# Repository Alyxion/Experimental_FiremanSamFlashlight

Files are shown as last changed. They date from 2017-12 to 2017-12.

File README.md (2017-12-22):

# Fireman Sam Flashlight #

In 2016 i experimented a lot with Fischertechnik, Arduino and microelectronics in general.

Because my son Maximilian was a big fan of Fireman Sam at this time as nearly every boy at his age, I decided that if I anyway want to build something, it's going to be a Fireman Sam Flashlight including everything a child of 6 needs... so a sirene, at least 50 meters of light range and so on :).

The result including 5 high performance LEDs, 2 blue LEDs for the sirene, a piezo element which was able to play a sirene sound and the theme Melody of Fireman Sam and 3 buttons to adjust the mode, the brightness and to play the melody you can see below. Additionally I inserted a button between the lithium-ion battery and the board to be able to toggle it of completely.

In a practice test the flashlight was really "evil"... unfortunately the smartphone's sensitivity was not fine enough to capture it in a picture, but the range was about 100 meters and it was by far brighter than the stock flashlight we owned before. Of course it could not compare to really high performance, cooled flashlights, but it was really impressing what you can build in such a short period of time completely from scratch.

---

### The soldering and connection scheme before the soldering action ###
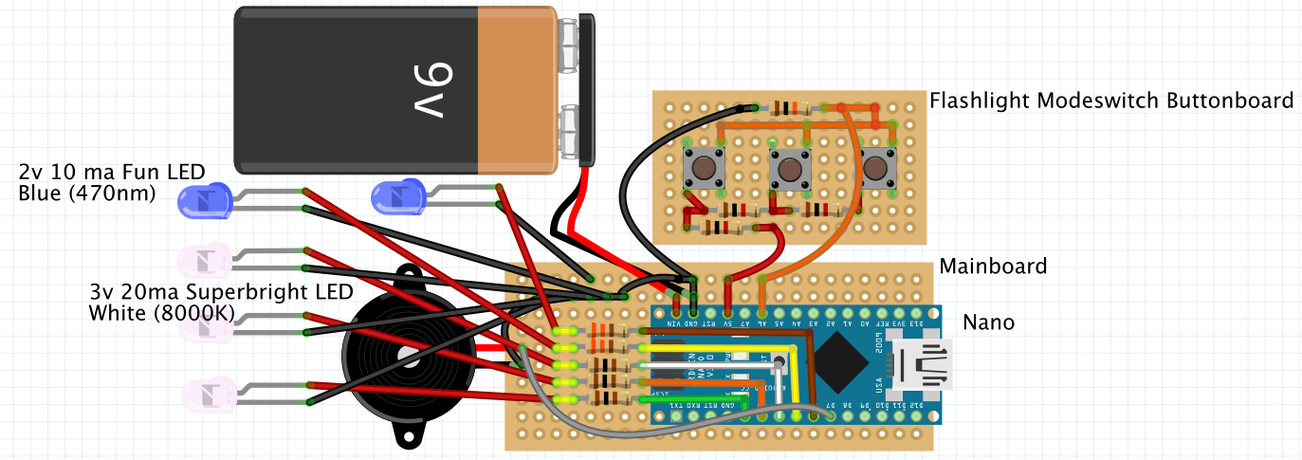
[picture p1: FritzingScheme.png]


### Upside of the result ###

It's not 100% matching the scheme above because I decided to add another 2 white LEDs in the testing phase for an additional 40% of brightness.

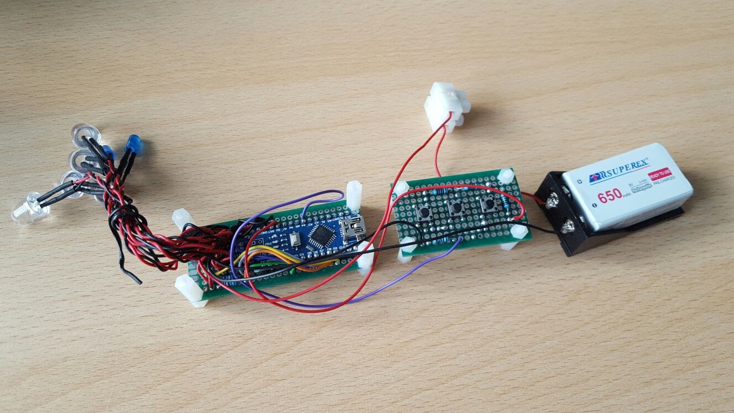
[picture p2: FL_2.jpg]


### Down side of the result ###
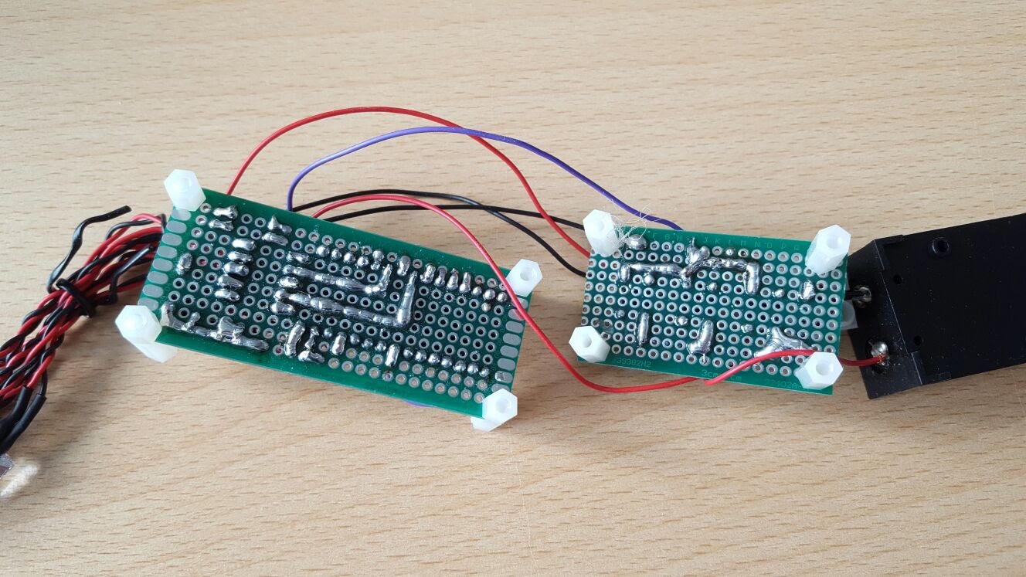
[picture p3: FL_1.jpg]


### Functionality test before glueing everything ###
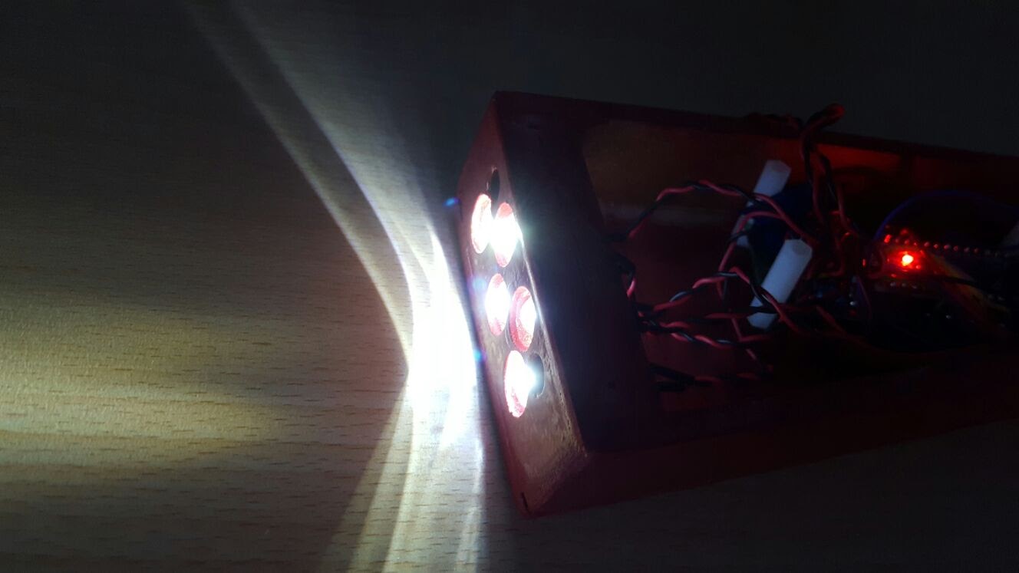
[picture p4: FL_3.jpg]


### All 7 LEDs and the board glued into the self-built housiung ###
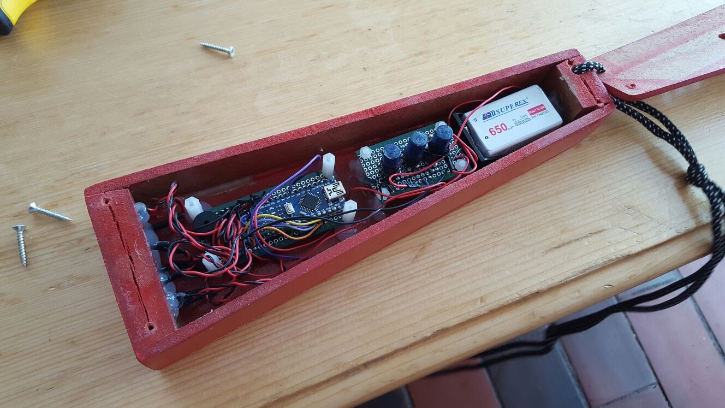
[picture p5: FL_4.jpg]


### Ready for action ###

Unfortunately the smartphone couldn't catch the real brightness, but it had about 100 meters total range, up to 50 meters you could still see someone else's face clearly... and you went blind instantly if you tried to look straight into the light ;).

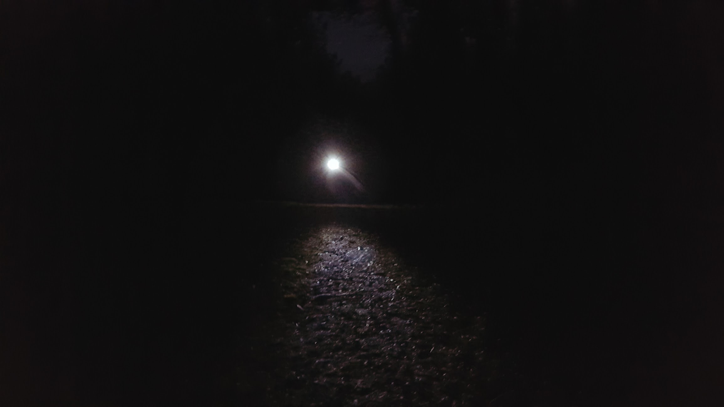
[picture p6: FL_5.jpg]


### Flashlight in "Sirene Mode" with Dalmatian Punkt (Dot) ###
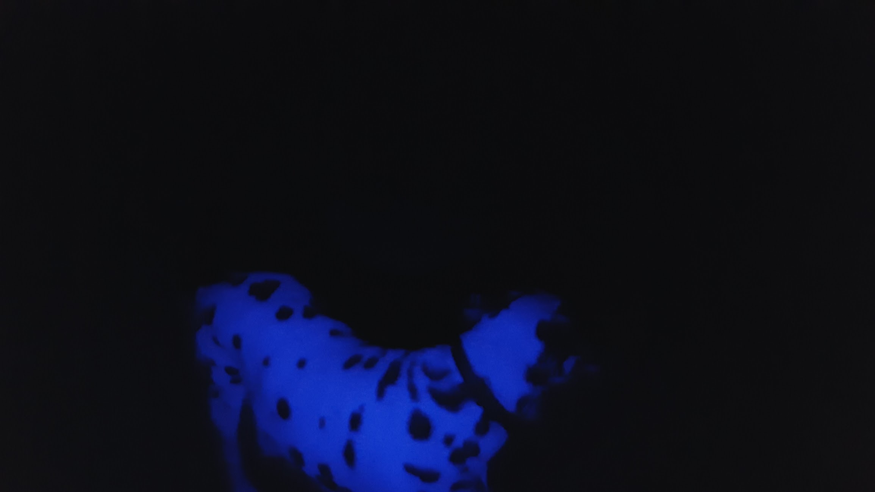
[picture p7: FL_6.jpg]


### Son Maximilian "investigating" the place of accident ;) ###
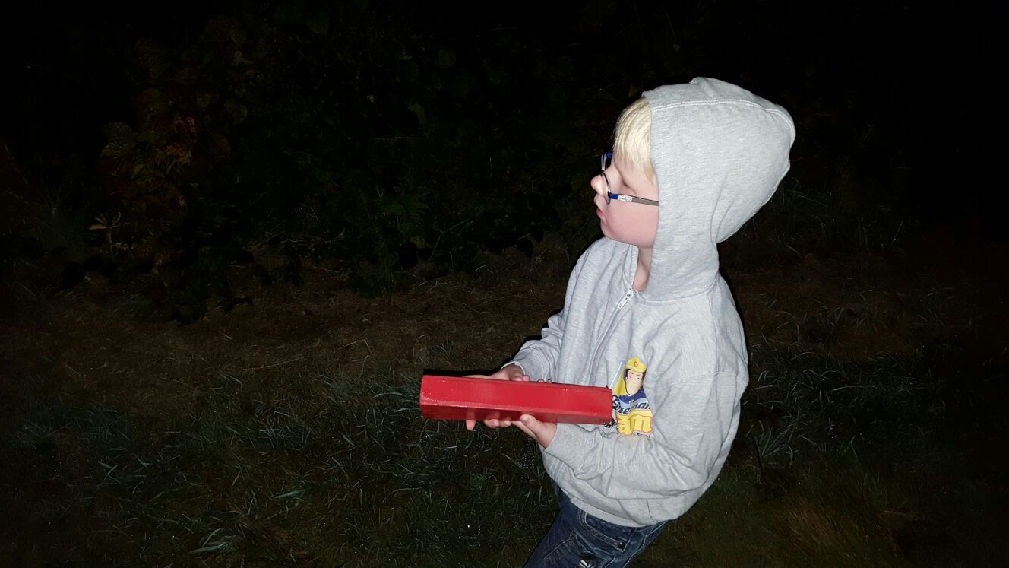
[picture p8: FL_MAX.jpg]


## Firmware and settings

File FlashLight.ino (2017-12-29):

/**
 * Firefighter Flashlight Arduino script
 *
 * Copyright (C) 2016 by Michael Ikemann
 * 
 *  Hardware setup:
 *  - White bright 30 mA leds at pins 2,3,4,7 and 8
 *  - Blue leds at pins 5 and 6
 *  - Piezo at pin 9
 *  - Analogue button input chain at pin 4, resistor chain using 1k/2k/3k for button 0, 1, 2 and 10k ground pulldown : +5V -> 1k -> button 0 -> 1k -> button 1 -> 1k button 2 -> (analogue 4 and (10k -> GND)
 *  
 *  Flash light switches between different modes when mode button is pressed, increases and decreases brightness or flashing frequency using + and - buttons and plays Fireman sam theme or an alarm if + or - are pressed and blue light mode
 */


// -------------------------------------------------------------------------------------

#include "pitches.h"  // for melodies

// -------------------------------------------------------------------------------------

#define FLASH_LIGHT_PIN_COUNT 5   ///< Total count of white LEDs
#define FIREFIGHTER_PIN_COUNT 2   ///< Total count of blue LEDs
#define PIEZO_PIN 9

const int gFlashLightPins[FLASH_LIGHT_PIN_COUNT] = {2,3,4,7,8};   ///< White LED pins
const int gFireLightPins[FIREFIGHTER_PIN_COUNT] = {5,6};          ///< Blue LED pins

#define BUTTON_TOLLERANCE 10  ///< Button tollerance, relative to 1024
#define BUTTON_INPUT 4        ///< Analogue pin 4
#define BUTTON_DELAY 25       ///< Debouncing delay

#define BLINK_SPEED 250               ///< Blue light blink speed
#define LIGHT_INTENSITY_STEPPING 10   ///< Stepping size of light intensity changing (0 = min, 100 = max)

// -------------------------------------------------------------------------------------

/** @brief Enumeration of flashlight modes */
enum class LightMode
{
  All,              ///< All white leds enabled
  JustOne,          ///< Just center led
  Inner,            ///< Just inner leds
  Walking,          ///< Knight righter mode (left to right and back)
  Switching,        ///< Switching between inner and outer
  Flashing,         ///< Flashing
  Emergency,        ///< Blue leds static
  EmergencyFlashing,  ///< Blue leds flashing
  Count             ///< Mode count
};

// -------------------------------------------------------------------------------------

/** @brief Enumeration of hardware buttons */
enum class FlashLightButton
{
  LightMode,  ///< Light mode button
  Plus,       ///< Plus button
  Minus,      ///< Minus button
  Count,      ///< Total button count
  None = -1   ///< No button / undefined state
};

// -------------------------------------------------------------------------------------

/** @brief Flashlight logic handling class */
class AFlashLight
{
protected:
  LightMode         mLightMode = LightMode::All;    ///< The current flash light mode
  int               miLightIntensity = 100;              ///< The current light intensity / flash speed
  const int         maiButtonAnalogValues[(int)FlashLightButton::Count] = {787, 852, 930};  ///< The analog values which are received if any of the buttons ia pressed
  FlashLightButton  mCurButton = FlashLightButton::None;  ///< The currently pressed button
  long              mlLastButtonChange = 0;               ///< The last button change tick
  long              mlLastButtonTriggered = 0;            ///< The last button trigger tick

public:
  //! Setups the flashlight
  void Setup();

  //! Updates the light and blinking states
  void UpdateLightStates();

  //! Handles the analogue input and triggers a button press when detected
  void EvaluateButtons();

  //! Handles the press of given button type
  /** @param [in] Button The button being pressed, @see FlashLightButton */
  void HandleButton(const FlashLightButton Button);

  //! Plays the Fireman Sam melody
  void PlayFiremanSam();

  //! Plays one of two alarm sounds
  /** @param [in] Style The style, either 0 or 1 atm */
  void PlayAlarm(const int Style);
};

// -------------------------------------------------------------------------------------

AFlashLight gFlashLight;   ///< Global flashlight object

// -------------------------------------------------------------------------------------

// Startup callback
void setup() {
  Serial.begin(9600);
  gFlashLight.Setup();
}

// .....................................................................................

// Main loop handler callback
void loop() 
{
  gFlashLight.EvaluateButtons();
  gFlashLight.UpdateLightStates();
}

// .....................................................................................

// Setups the flashlight
void AFlashLight::Setup()
{
  for(int i=0; i<FLASH_LIGHT_PIN_COUNT; ++i)
  {
    pinMode(gFlashLightPins[i], OUTPUT);
  }

  for(int i=0; i<FIREFIGHTER_PIN_COUNT; ++i)
  {
    pinMode(gFireLightPins[i], OUTPUT);
  }  

  noTone(PIEZO_PIN); // stopt das Spielen des Tons
}

// .....................................................................................

// Updates the light and blinking states
void AFlashLight::UpdateLightStates()
{  
  int lightInt;

  if(mLightMode==LightMode::Flashing) // Use intensity for frequency in flashing mode
  {
    int interval = miLightIntensity*5;
    lightInt = millis()%(interval*2)/interval ? HIGH : LOW;
  }
  else
  {
    lightInt = micros()%10000>=(100-miLightIntensity)*100;
  }
  
  int off = millis()%1600/200;
  if(off>4)
    off = 4-(off-4);

  if(mLightMode==LightMode::Walking)
  {
    switch(off)
    {
      case 0: off = 3; break;
      case 1: off = 2; break;
      case 2: off = 1; break;
      case 3: off = 0; break;
      case 4: off = 4; break;
    }
  }

  // white center led
  digitalWrite(gFlashLightPins[0], mLightMode==LightMode::Flashing || mLightMode==LightMode::Inner || (mLightMode==LightMode::Walking && off==0) || (mLightMode==LightMode::Switching && millis()%(BLINK_SPEED*2)/BLINK_SPEED==0) ||mLightMode==LightMode::All ? lightInt : LOW);
  // left inner
  digitalWrite(gFlashLightPins[1], mLightMode==LightMode::Flashing || mLightMode<=LightMode::Inner || (mLightMode==LightMode::Walking && off==1) ||(mLightMode==LightMode::Switching && millis()%(BLINK_SPEED*2)/BLINK_SPEED==0) ||mLightMode==LightMode::All ? lightInt : LOW);
  // right inner
  digitalWrite(gFlashLightPins[2], mLightMode==LightMode::Flashing || mLightMode==LightMode::Inner || (mLightMode==LightMode::Walking && off==2) ||(mLightMode==LightMode::Switching && millis()%(BLINK_SPEED*2)/BLINK_SPEED==0) || mLightMode==LightMode::All ? lightInt : LOW);
  // left outer
  digitalWrite(gFlashLightPins[3], mLightMode==LightMode::Flashing || mLightMode==LightMode::All || (mLightMode==LightMode::Walking && off==3) ||(mLightMode==LightMode::Switching && millis()%(BLINK_SPEED*2)/BLINK_SPEED==1) ? lightInt : LOW);
  // right outer
  digitalWrite(gFlashLightPins[4], mLightMode==LightMode::Flashing || mLightMode==LightMode::All || (mLightMode==LightMode::Walking && off==4) ||(mLightMode==LightMode::Switching && millis()%(BLINK_SPEED*2)/BLINK_SPEED==1) ? lightInt : LOW);

  // blue leds
  digitalWrite(gFireLightPins[0], mLightMode==LightMode::Emergency || (mLightMode==LightMode::EmergencyFlashing && millis()%(BLINK_SPEED*2)/BLINK_SPEED==1)  ? HIGH : LOW);
  digitalWrite(gFireLightPins[1], mLightMode==LightMode::Emergency || (mLightMode==LightMode::EmergencyFlashing && millis()%(BLINK_SPEED*2)/BLINK_SPEED==0) ? HIGH : LOW);
}

// .....................................................................................

// Handles the analogue input and triggers a button press when detected
void AFlashLight::EvaluateButtons()
{
  int buttonState = analogRead(BUTTON_INPUT);
  FlashLightButton newButton = FlashLightButton::None;

  if(buttonState>BUTTON_TOLLERANCE)
  {
    for(int i=0; i<(int)FlashLightButton::Count; ++i)
    {
      if(abs(buttonState-maiButtonAnalogValues[i])<BUTTON_TOLLERANCE)
      {
        newButton = (FlashLightButton)i;
      }
    }
  }

  if(mCurButton!=newButton)
  {
    mCurButton = newButton;
    mlLastButtonChange = millis();
    mlLastButtonTriggered = 0;
  }

   if(mCurButton!=FlashLightButton::None && mlLastButtonTriggered==0 && millis()-mlLastButtonChange>BUTTON_DELAY)
   {
    HandleButton(mCurButton);
   }
}

// .....................................................................................

// Handles the press of given button type
void AFlashLight::HandleButton(const FlashLightButton Button)
{
  mlLastButtonTriggered = millis();
  Serial.println((int)mCurButton);

  if(Button==FlashLightButton::LightMode)
  {
    mLightMode = (LightMode)(((int)mLightMode+1)%(int)LightMode::Count);
    miLightIntensity = 100;
  }

  if((mLightMode==LightMode::Emergency || mLightMode==LightMode::EmergencyFlashing) && (Button==FlashLightButton::Plus || Button==FlashLightButton::Minus))
  {
    if(Button==FlashLightButton::Plus)
    {
    PlayFiremanSam();  
    }
    else
    {
      PlayAlarm(mLightMode==LightMode::Emergency ? 1 : 0);
    }
  }
  else
  {
    if(Button==FlashLightButton::Plus)
    {
      miLightIntensity += LIGHT_INTENSITY_STEPPING;
      if(miLightIntensity>100)
      {
        miLightIntensity = 100;
      }
    }
    if(mCurButton==FlashLightButton::Minus)
    {
      miLightIntensity -= LIGHT_INTENSITY_STEPPING;
      if(miLightIntensity<LIGHT_INTENSITY_STEPPING)
        miLightIntensity = LIGHT_INTENSITY_STEPPING;
    }
  }
}

// .....................................................................................

// Plays the Fireman Sam melody
void AFlashLight::PlayFiremanSam()
{
  // notes in the melody:
  int melody[] = {
    NOTE_F3, NOTE_C4, NOTE_F3, NOTE_C4, NOTE_F3, 
    NOTE_C4, NOTE_F3, NOTE_A3, NOTE_C4, NOTE_D4,
    NOTE_AS3, NOTE_A3, NOTE_C4, NOTE_D4,
    NOTE_A4, NOTE_G4, NOTE_F4, NOTE_E4, NOTE_D4,
    NOTE_D4, NOTE_G4, NOTE_E4,
    NOTE_A4, NOTE_G4, NOTE_F4, NOTE_E4, NOTE_D4,
    NOTE_D4, NOTE_G4, NOTE_F4, NOTE_E4, NOTE_D4,
    NOTE_E4, NOTE_F4  
  };

  // note durations: 4 = quarter note, 8 = eighth note, etc.:
  int noteDurations[] = {
    2, 2, 2, 2, 2, 
    2, 1, 2, 2, 2, 
    2, 2, 2, 1,
    2, 4, 4, 4, 1,
    2, 2, 1,
    2, 4, 4, 4, 1,
    2, 4, 4, 4, 4,
    2, 1
  };

  // iterate over the notes of the melody:
  for (int thisNote = 0; thisNote < sizeof(melody)/sizeof(int); thisNote++) {

    // to calculate the note duration, take one second
    // divided by the note type.
    //e.g. quarter note = 1000 / 4, eighth note = 1000/8, etc.
    int noteDuration = 1000 / noteDurations[thisNote];
    tone(PIEZO_PIN, melody[thisNote], noteDuration);

    // to distinguish the notes, set a minimum time between them.
    // the note's duration + 30% seems to work well:
    int pauseBetweenNotes = noteDuration * 1.30;
    for(int i=0; i<8; ++i)  // split pause to be able to update lights
    {
      delay(pauseBetweenNotes/8);  
      UpdateLightStates();    
    }
    // stop the tone playing:
    noTone(PIEZO_PIN); 
    delay(10);
  }
}

// .....................................................................................

// Plays one of two alarm sounds
void AFlashLight::PlayAlarm(const int Style)
{

  switch(Style)
  {
    case 0:
    {
      int delayTime = 400;
      int repetitions = 4;
    
      for(int i=0; i<4; ++i)
      {
        tone(PIEZO_PIN, 440*3, delayTime);

        for(int turn=0; turn<8; ++turn)
        {
          delay(delayTime/8);
          UpdateLightStates();
        }
        
        noTone(PIEZO_PIN);
        
        tone(PIEZO_PIN, 523*4, delayTime);

        for(int turn=0; turn<8; ++turn)
        {
          delay(delayTime/8);
          UpdateLightStates();
        }

        noTone(PIEZO_PIN);

        UpdateLightStates();
      }
    } break;
    
    case 1:
    {
     int speed = 10;
    
      for(int rep=0; rep<3; ++rep)
      {
        for (int x = 0; x < 100; x++)
        { 
          tone(PIEZO_PIN, 300 + x*60, speed);
          for(int turn=0; turn<8; ++turn)
          {
            delay(speed/8);
            UpdateLightStates();
          }        
          noTone(PIEZO_PIN);
        }   
        for (int x = 99; x>=0; --x)
        { 
          tone(PIEZO_PIN, 300 + x*60, speed);
          for(int turn=0; turn<8; ++turn)
          {
            delay(speed/8);
            UpdateLightStates();
          }        
          noTone(PIEZO_PIN);
        }
      }   
    } break;
  }
}
